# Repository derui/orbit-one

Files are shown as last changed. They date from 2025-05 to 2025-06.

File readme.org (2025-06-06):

* Orbit One
This is schematics for hand-made keyboard.

- Unified body, no split
- Modified Alice Layout
- 17mm key pitch
- Have 2 encoders side by side
- Installed glidepoint touch pad
- Acryl Gasket mount case

* PCB Data
This project uses kicad and PCB Data opened below.

- https://github.com/Salicylic-acid3/KiCAD_FootPrint

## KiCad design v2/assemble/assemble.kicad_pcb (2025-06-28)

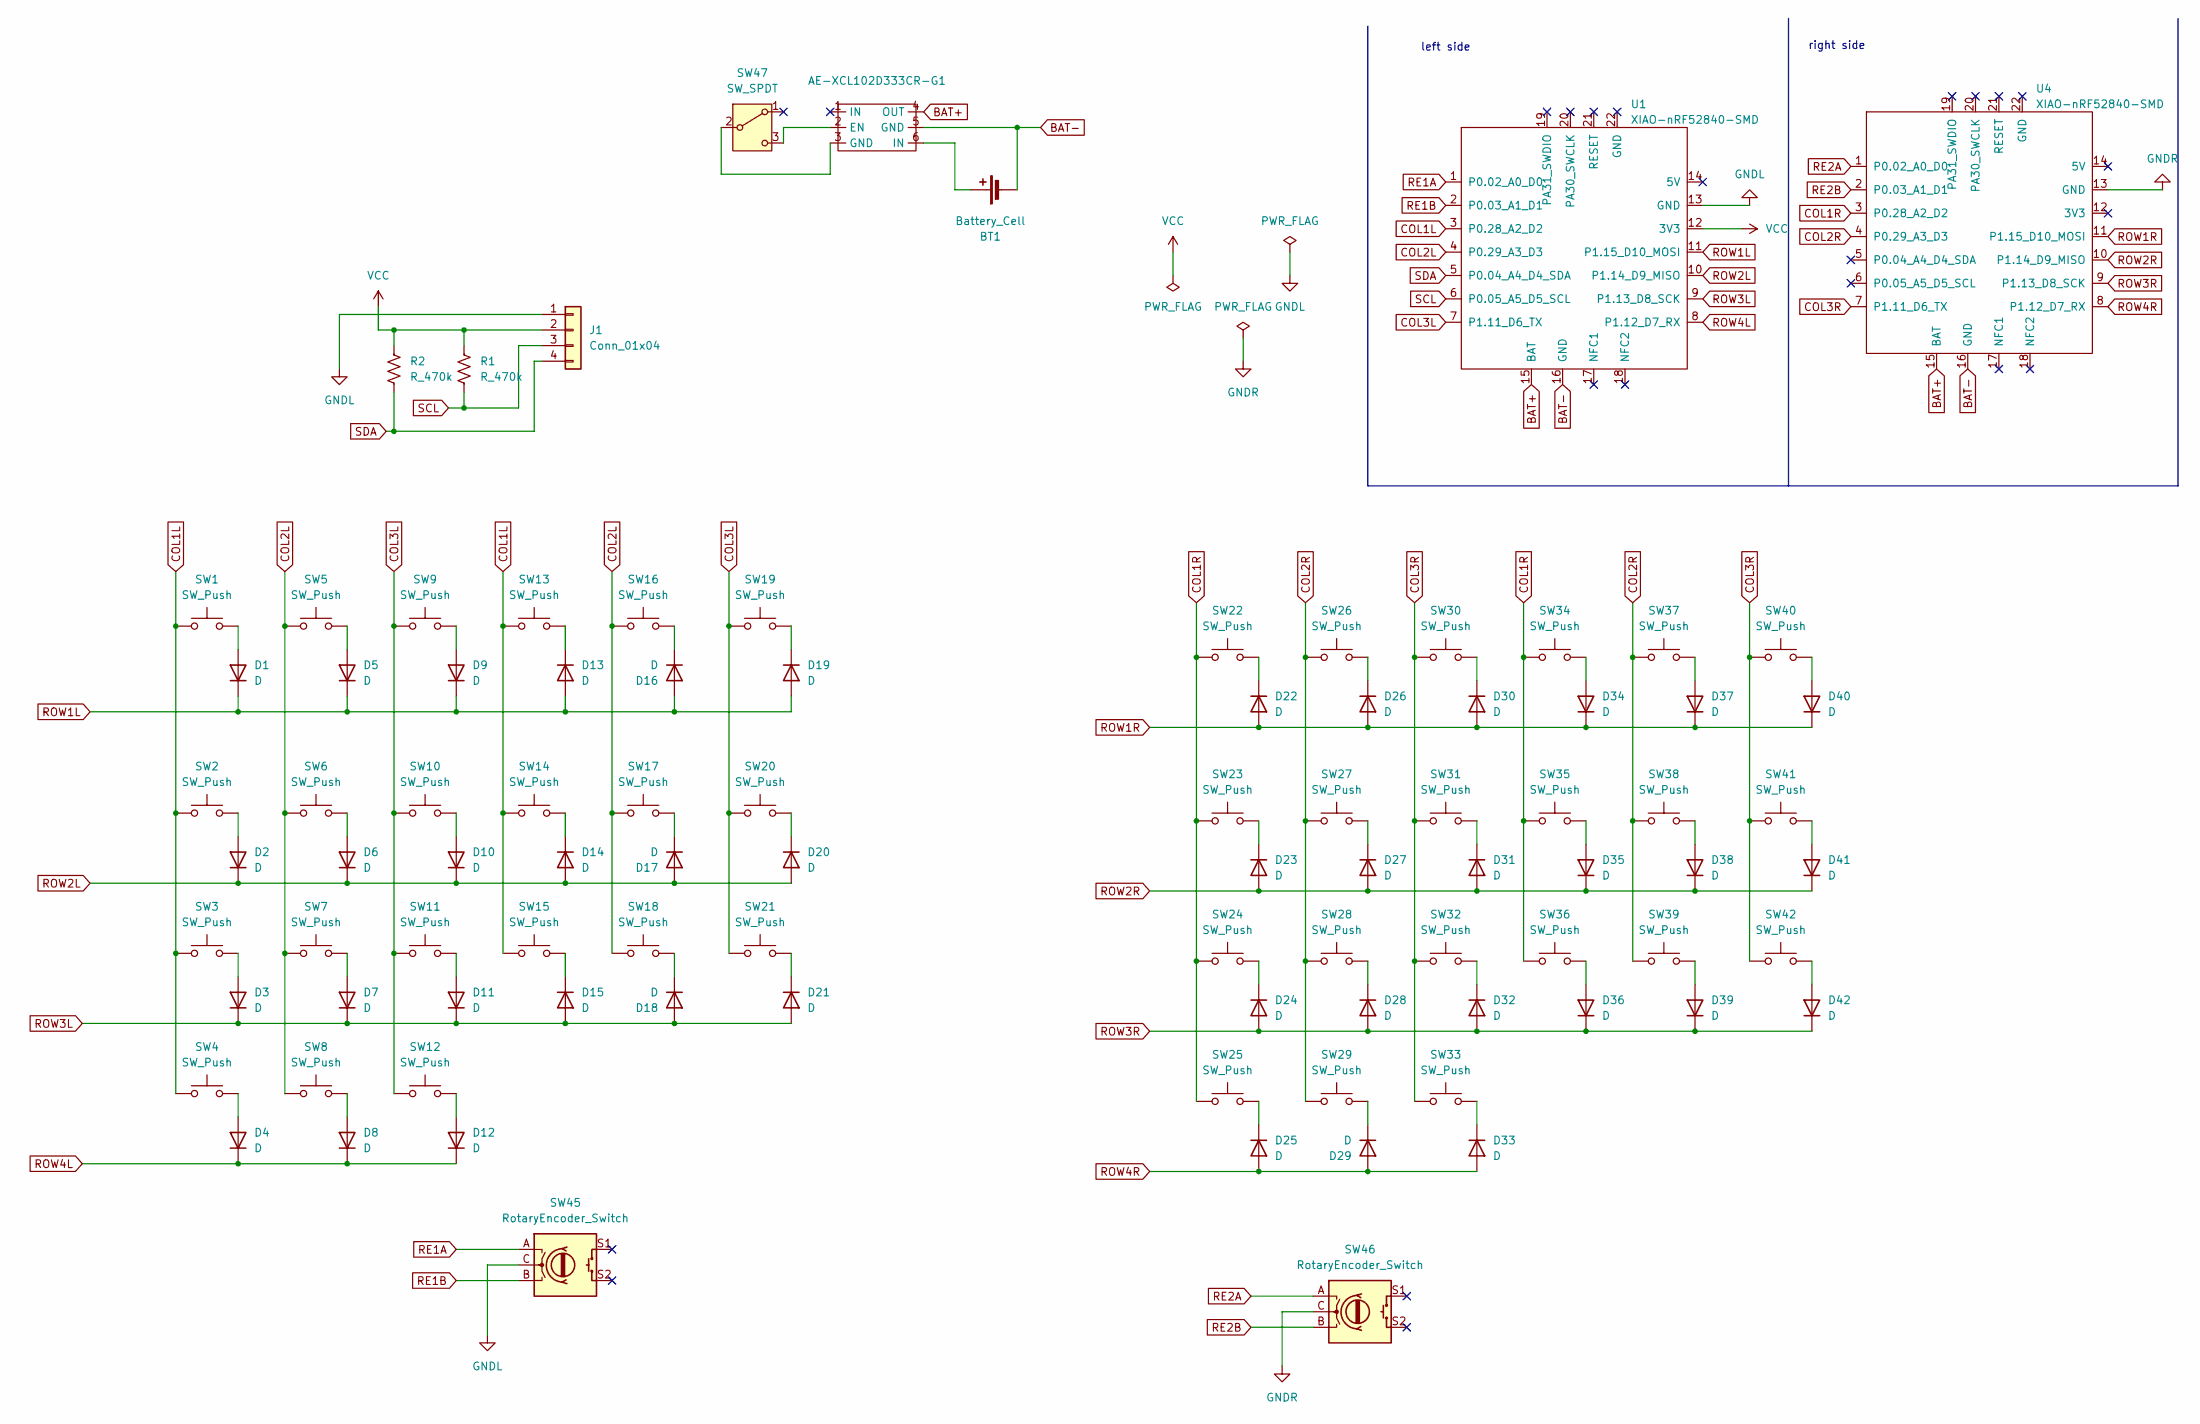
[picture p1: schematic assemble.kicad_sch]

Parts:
AE-XCL102D333CR-G1: AE-XCL102D333CR-G
BT1: Battery_Cell; Battery_AAA
D1, D2, D3, D4, D5, D6, D7, D8, D9, D10, D11, D12, D13, D14, D15, D16, D17, D18, D19, D20, D21, D22, D23, D24, D25, D26, D27, D28, D29, D30, D31, D32, D33, D34, D35, D36, D37, D38, D39, D40, D41, D42: D; Diode_SMD
J1: Conn_01x04; PinSocket_1x04_P2.54mm_Vertical
R1, R2: R_470k; R_Axial_DIN0204_L3.6mm_D1.6mm_P5.08mm_Horizontal
SW1, SW2, SW3, SW4, SW5, SW6, SW7, SW8, SW9, SW10, SW11, SW12, SW13, SW14, SW15, SW16, SW17, SW18, SW19, SW20, SW21, SW22, SW23, SW24, SW25, SW26, SW27, SW28, SW29, SW30, SW31, SW32, SW33, SW34, SW35, SW36, SW37, SW38, SW39, SW40, SW41, SW42: SW_Push; CherryMX-HotSwap-1u_17
SW45, SW46: RotaryEncoder_Switch; RotaryEncoder_EC12E
SW47: SW_SPDT; TGSW_MSK-12D19
U1, U4: XIAO-nRF52840-SMD

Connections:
BAT+: AE-XCL102D333CR-G1.4 (OUT), U1.15 (BAT), U4.15 (BAT)
BAT-: AE-XCL102D333CR-G1.5 (GND), BT1.2 (-), U1.16 (GND), U4.16 (GND)
COL1L: SW1.1, SW2.1, SW3.1, SW4.1, SW13.1, SW14.1, SW15.1, U1.3 (P0.28_A2_D2)
COL1R: SW22.1, SW23.1, SW24.1, SW25.1, SW34.1, SW35.1, SW36.1, U4.3 (P0.28_A2_D2)
COL2L: SW5.1, SW6.1, SW7.1, SW8.1, SW16.1, SW17.1, SW18.1, U1.4 (P0.29_A3_D3)
COL2R: SW26.1, SW27.1, SW28.1, SW29.1, SW37.1, SW38.1, SW39.1, U4.4 (P0.29_A3_D3)
COL3L: SW9.1, SW10.1, SW11.1, SW12.1, SW19.1, SW20.1, SW21.1, U1.7 (P1.11_D6_TX)
COL3R: SW30.1, SW31.1, SW32.1, SW33.1, SW40.1, SW41.1, SW42.1, U4.7 (P1.11_D6_TX)
GNDL: J1.1, SW45.C, U1.13 (GND)
GNDR: SW46.C, U4.13 (GND)
unnamed: AE-XCL102D333CR-G1.2 (EN), SW47.3 (C)
unnamed: AE-XCL102D333CR-G1.6 (IN), BT1.1 (+)
unnamed: D1.2 (A), SW1.2
unnamed: D2.2 (A), SW2.2
unnamed: D3.2 (A), SW3.2
unnamed: D4.2 (A), SW4.2
unnamed: D5.2 (A), SW5.2
unnamed: D6.2 (A), SW6.2
unnamed: D7.2 (A), SW7.2
unnamed: D8.2 (A), SW8.2
unnamed: D9.2 (A), SW9.2
unnamed: D10.2 (A), SW10.2
unnamed: D11.2 (A), SW11.2
unnamed: D12.2 (A), SW12.2
unnamed: D13.1 (K), SW13.2
unnamed: D14.1 (K), SW14.2
unnamed: D15.1 (K), SW15.2
unnamed: D16.1 (K), SW16.2
unnamed: D17.1 (K), SW17.2
unnamed: D18.1 (K), SW18.2
unnamed: D19.1 (K), SW19.2
unnamed: D20.1 (K), SW20.2
unnamed: D21.1 (K), SW21.2
unnamed: D22.1 (K), SW22.2
unnamed: D23.1 (K), SW23.2
unnamed: D24.1 (K), SW24.2
unnamed: D25.1 (K), SW25.2
unnamed: D26.1 (K), SW26.2
unnamed: D27.1 (K), SW27.2
unnamed: D28.1 (K), SW28.2
unnamed: D29.1 (K), SW29.2
unnamed: D30.1 (K), SW30.2
unnamed: D31.1 (K), SW31.2
unnamed: D32.1 (K), SW32.2
unnamed: D33.1 (K), SW33.2
unnamed: D34.2 (A), SW34.2
unnamed: D35.2 (A), SW35.2
unnamed: D36.2 (A), SW36.2
unnamed: D37.2 (A), SW37.2
unnamed: D38.2 (A), SW38.2
unnamed: D39.2 (A), SW39.2
unnamed: D40.2 (A), SW40.2
unnamed: D41.2 (A), SW41.2
unnamed: D42.2 (A), SW42.2
unnamed: AE-XCL102D333CR-G1.3 (GND), SW47.2 (B)
RE1A: SW45.A, U1.1 (P0.02_A0_D0)
RE1B: SW45.B, U1.2 (P0.03_A1_D1)
RE2A: SW46.A, U4.1 (P0.02_A0_D0)
RE2B: SW46.B, U4.2 (P0.03_A1_D1)
ROW1L: D1.1 (K), D5.1 (K), D9.1 (K), D13.2 (A), D16.2 (A), D19.2 (A), U1.11 (P1.15_D10_MOSI)
ROW1R: D22.2 (A), D26.2 (A), D30.2 (A), D34.1 (K), D37.1 (K), D40.1 (K), U4.11 (P1.15_D10_MOSI)
ROW2L: D2.1 (K), D6.1 (K), D10.1 (K), D14.2 (A), D17.2 (A), D20.2 (A), U1.10 (P1.14_D9_MISO)
ROW2R: D23.2 (A), D27.2 (A), D31.2 (A), D35.1 (K), D38.1 (K), D41.1 (K), U4.10 (P1.14_D9_MISO)
ROW3L: D3.1 (K), D7.1 (K), D11.1 (K), D15.2 (A), D18.2 (A), D21.2 (A), U1.9 (P1.13_D8_SCK)
ROW3R: D24.2 (A), D28.2 (A), D32.2 (A), D36.1 (K), D39.1 (K), D42.1 (K), U4.9 (P1.13_D8_SCK)
ROW4L: D4.1 (K), D8.1 (K), D12.1 (K), U1.8 (P1.12_D7_RX)
ROW4R: D25.2 (A), D29.2 (A), D33.2 (A), U4.8 (P1.12_D7_RX)
SCL: J1.3, R1.2, U1.6 (P0.05_A5_D5_SCL)
SDA: J1.4, R2.2, U1.5 (P0.04_A4_D4_SDA)
VCC: J1.2, R1.1, R2.1, U1.12 (3V3)

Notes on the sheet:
left side
right side

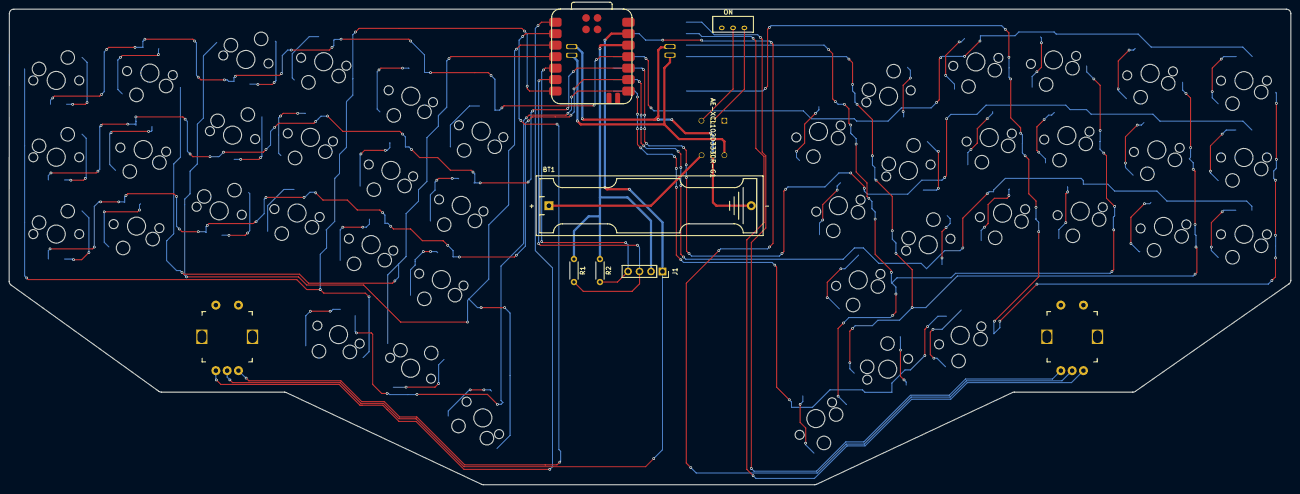
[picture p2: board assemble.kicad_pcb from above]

Board: 2 copper layers, 283.6 x 105.3 mm, 94 parts (1 on the bottom side), 70 nets.

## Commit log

2025-05-17 feat: add schematic
    [assemble.kicad_pcb, assemble.kicad_sch]
2025-05-18 feat: add pcb data
    [assemble.kicad_pcb, assemble.kicad_sch]
2025-05-18 feat: re-annotation
    [assemble.kicad_pcb]
2025-05-18 fix: orientations
    [assemble.kicad_pcb]
2025-05-18 feat: add edge cut
    [assemble.kicad_pcb]
2025-05-25 feat: add switch plate
    [assemble.kicad_pcb, switch_plate.kicad_pcb, switch_plate.kicad_sch]
2025-05-29 feat: change screw
    [assemble.kicad_pcb, switch_plate.kicad_pcb]
2025-05-31 feat: wiring
    [assemble.kicad_pcb]
2025-05-31 fix: screw point
    [assemble.kicad_pcb, switch_plate.kicad_pcb]
2025-05-31 fix: footprint
    [switch_plate.kicad_pcb]
2025-06-07 feat: add bottom form
    [bottom_form.kicad_pcb, bottom_form.kicad_sch]
2025-06-15 fix: invalid I2C connection
    [assemble.kicad_pcb]
2025-06-22 feat: add v2
    [assemble.kicad_pcb, assemble.kicad_sch, bottom_form.kicad_pcb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]
2025-06-26 feat: implement v2 pcb
    [assemble.kicad_pcb, assemble.kicad_sch]
2025-06-28 fix: plot setting
    [assemble.kicad_pcb]
